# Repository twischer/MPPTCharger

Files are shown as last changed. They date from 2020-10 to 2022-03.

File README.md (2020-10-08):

# MPPTCharger
Maximum Power Point Tracking Charge Controller for ESP8266

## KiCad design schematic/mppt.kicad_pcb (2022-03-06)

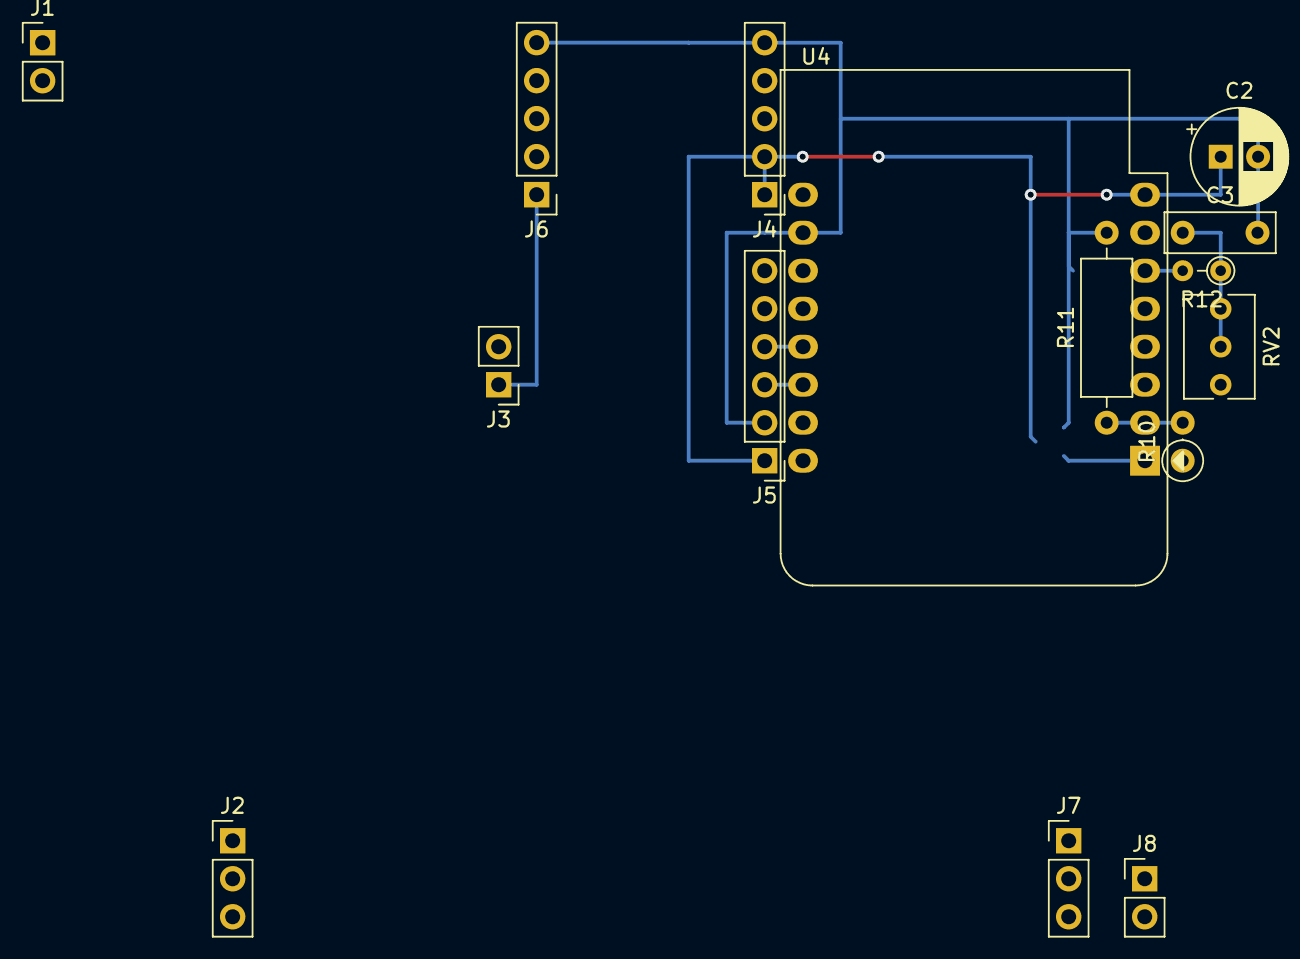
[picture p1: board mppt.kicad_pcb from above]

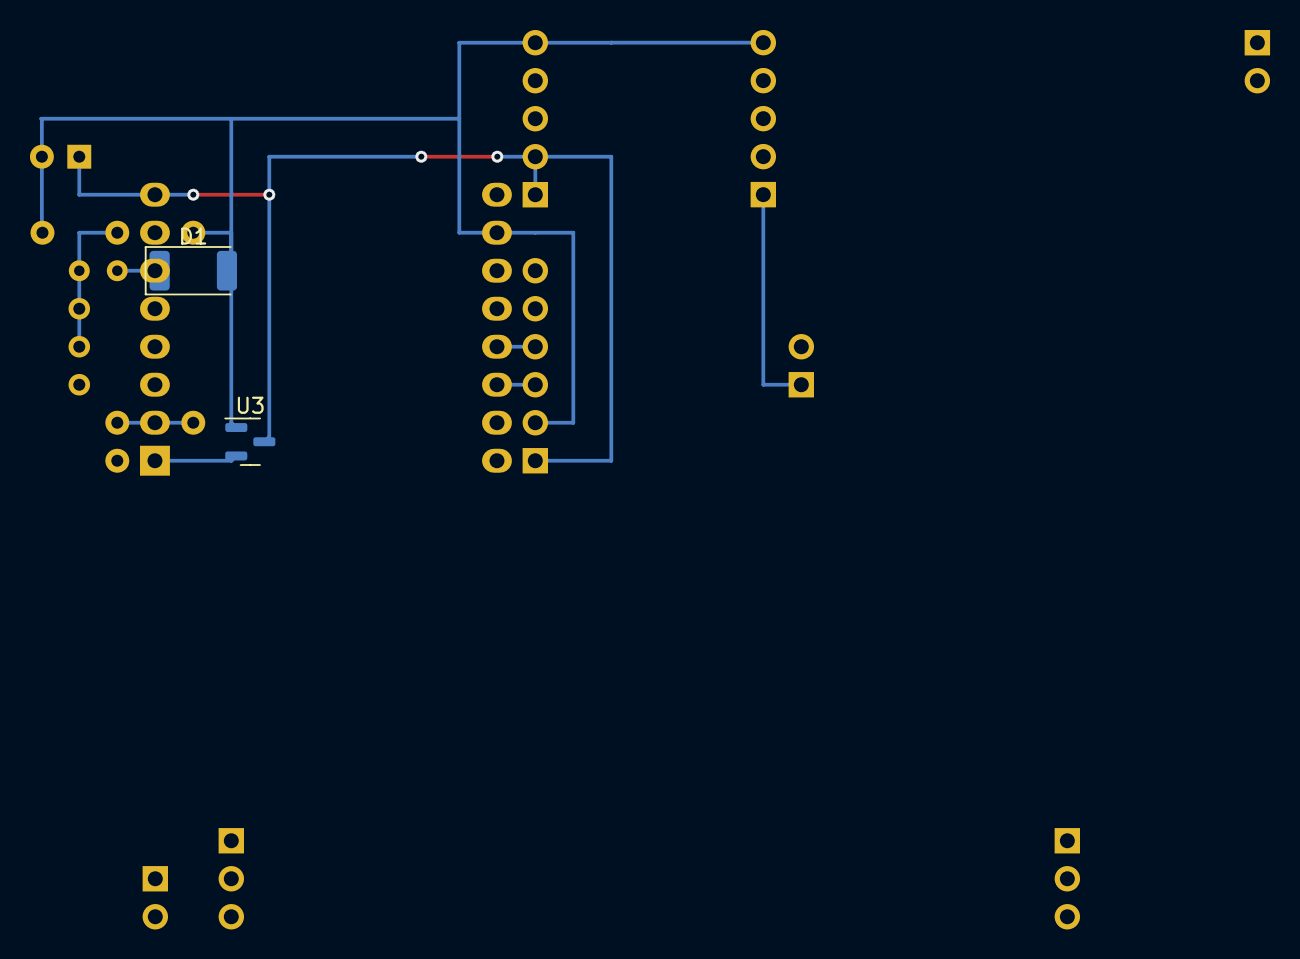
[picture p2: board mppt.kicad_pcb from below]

Board: 2 copper layers, 17 parts (2 on the bottom side), 12 nets.

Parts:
C2: 100µ; CP_Radial_D6.3mm_P2.50mm
C3: 1µ; C_Rect_L7.2mm_W2.5mm_P5.00mm_FKS2_FKP2_MKS2_MKP2
D1: 3V6; D_2010_5025Metric
J1: Solar; PinHeader_1x02_P2.54mm_Vertical
J2: TL494-IN; PinHeader_1x03_P2.54mm_Vertical
J3: INA219; PinHeader_1x02_P2.54mm_Vertical
J4: MP2307-OUT; PinHeader_1x05_P2.54mm_Vertical
J5: INA219; PinHeader_1x06_P2.54mm_Vertical
J6: MP2307-IN; PinHeader_1x05_P2.54mm_Vertical
J7: TL494-OUT-42V-3A; PinHeader_1x03_P2.54mm_Vertical
J8: LiIon-36V; PinHeader_1x02_P2.54mm_Vertical
R10: 120k; R_Axial_DIN0207_L6.3mm_D2.5mm_P2.54mm_Vertical
R11: 2k2; R_Axial_DIN0309_L9.0mm_D3.2mm_P12.70mm_Horizontal
R12: 1k2; R_Axial_DIN0204_L3.6mm_D1.6mm_P2.54mm_Vertical
RV2: 10k; Potentiometer_Bourns_3266Y_Vertical
U3: MAX809S; SOT-23
U4: WeMos_D1_mini; WEMOS_D1_mini_light

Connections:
GND: C2.2, C3.2, D1.2 (A), J1.1, J2.3, J4.5, J5.2, J6.5, R11.2, U3.1 (GND), U4.10 (GND)
unnamed: C2.1, J4.1, J4.2, J5.1, U3.3 (VCC), U4.8 (3V3)
unnamed: C3.1, R12.1, RV2.2, RV2.3
unnamed: D1.1 (K), R12.2, U4.6 (MOSI/D7)
unnamed: J7.1, R10.1
unnamed: J1.2, J3.2, J5.6
unnamed: J2.1, J3.1, J5.5, J6.1
unnamed: J5.3, U4.14 (SCL/D1)
unnamed: J5.4, U4.13 (SDA/D2)
unnamed: J7.3, J8.2
unnamed: R10.2, R11.1, U4.2 (A0)
unnamed: U3.2 (RESET), U4.1 (~RST)

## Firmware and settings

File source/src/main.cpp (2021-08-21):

#ifdef ESP8266
#include <ESP8266WiFi.h>
#else
#include <WiFi.h>
#endif

#include <wiring_private.h>
#include <GDBStub.h>
#include <TelnetStream.h>
#include <StreamUtils.h>
#include <WiFiManager.h>
#include <INA219Calc.hpp>
#include "SoftwareWatchdog.h"
#include "ADCReader.hpp"
#include "MPPT.hpp"
#include "MPPTSigmaDeltaOutput.hpp"

static const char AP_SSID[] = "MPPTCharger";
static const char AP_PASSWORD[] = "zweiundvierzig";

static const bool ENABLE_GDB_STUB = false;

static const uint8_t INA219_SCL = 2;
static const uint8_t INA219_SDA = 13;
static const float SHUNT_R = 0.005;
static const float SHUNT_MAX_V = 0.04;
static const float MAX_CURRENT = SHUNT_MAX_V / SHUNT_R;

static const float ADC_VOLTAGE_OUT_MIN = 33.0;
static const float ADC_VOLTAGE_OUT_MAX = 42.0;
static const float ADC_VOLTAGE_OUT_PROTECT = ADC_VOLTAGE_OUT_MAX * 1.01; /* max + 1% */

SoftwareWatchdog swWatchdog;
ADCReader adcs;
INA219Calc ina219;
/* GPIO12 is connected to dead time control of TL494 */
const uint8_t TL494_DTC_PIN = 12;
MPPTSigmaDeltaOutput mpptOutput(TL494_DTC_PIN);
MPPT mppt(mpptOutput);
WriteBufferingStream telnet(TelnetStream, 160);


static void outSwitchOff()
{
	digitalWrite(TL494_DTC_PIN, HIGH);
	pinMode(TL494_DTC_PIN, OUTPUT);
}

RF_PRE_INIT() {
	/* disable step up/down converter to keep initial solar power for ESP boot up */
	outSwitchOff();
}

/* do not reset GPIO pins between RF_PRE_INIT() and setup() */
void resetPins() {}

void setup()
{
	Serial.begin(115200);
	Serial.print("Reset reason: ");
	Serial.println(ESP.getResetInfo());

	if (ENABLE_GDB_STUB) {
		/* See https://arduino-esp8266.readthedocs.io/en/latest/gdb.html for usage */
		gdbstub_init();
	}

	WiFiManager wifiManager;
	/* do not block in Web interface when STA WiFi not available */
	wifiManager.setConfigPortalTimeout(1);
	/* connecting to wifi might take some time */
	swWatchdog.feed();
	wifiManager.autoConnect(AP_SSID, AP_PASSWORD);
	swWatchdog.feed();

	Wire.begin(INA219_SDA, INA219_SCL);
	ina219.begin();
	ina219.configure(INA219::RANGE_32V, INA219::GAIN_1_40MV, INA219::ADC_64SAMP,
			INA219::ADC_64SAMP, INA219::CONT_SH_BUS);
	ina219.calibrate(SHUNT_R, SHUNT_MAX_V, D_V_BUS_MAX, MAX_CURRENT);

	TelnetStream.begin();
}

static void updateTelnet()
{
	// TODO only execute the following when a client is connected */
	//if (!TelnetStream.available())
	//	return;

	/* clear screen and move to home position */
	telnet.print("\033[H\033[2J");
	telnet.println("ESP8266 MPPT Charger");

	const uint32_t seconds = millis() / 1000;
	const uint32_t minutes = seconds / 60;
	const uint32_t hours = minutes / 60;
	telnet.printf("Uptime:\t%02u:%02u:%02uh", hours, (minutes % 60), (seconds % 60));
	telnet.println();

	telnet.print("Uin:\t");
	telnet.print(ina219.busVoltage());
	telnet.println("V");

	telnet.print("Iin:\t");
	telnet.print(ina219.shuntCurrent());
	telnet.println("A");

	telnet.print("Pin:\t");
	telnet.print(ina219.busPower());
	telnet.println("W");

	telnet.print("Ein:\t");
	telnet.print(ina219.busEnergy());
	telnet.println("Wh");

	telnet.print("Uout:\t");
	const float uout = adcs.get(ADC_VOLTAGE_OUT);
	static bool outProtected = false;
	if (uout > ADC_VOLTAGE_OUT_PROTECT) {
		outSwitchOff();
		outProtected = true;
	}
	telnet.print(uout);
	telnet.print("V ");

	static const float voltage2level = 100 / (ADC_VOLTAGE_OUT_MAX - ADC_VOLTAGE_OUT_MIN);
	const float uoutBattStart = uout - ADC_VOLTAGE_OUT_MIN;
	const float chargeLevel = (uoutBattStart > 0) ? (uoutBattStart * voltage2level) : 0.0;

	telnet.print(chargeLevel);
	telnet.println("%");

	telnet.print("PWMout:\t");
	if (outProtected)
		telnet.println("PROTECTED!!!");
	else {
		const float pwm = mppt.getPwmLevel();
		telnet.print(pwm);
		telnet.print("% ");

		static float lastPWM = 0.0;
		if (pwm > lastPWM)
			telnet.println("u");
		else
			telnet.println("d");
		lastPWM = pwm;
	}
	telnet.flush();
}

void loop()
{
	switch (TelnetStream.read()) {
	case 'w':
	case 'W': {
		WiFiManager wifiManager;
		swWatchdog.disable();
		/* this call blocks until a WLAN was selected */
		wifiManager.startConfigPortal(AP_SSID, AP_PASSWORD);
		swWatchdog.enable();
		break;
	}
	case 'R':
		TelnetStream.stop();
		delay(100);
		ESP.restart();
		break;
	case 'e':
	case 'q':
	case 'c':
	case 'C':
		TelnetStream.println("bye bye");
		TelnetStream.flush();
		TelnetStream.stop();
		break;
	}


	const unsigned long now = millis();
	static unsigned long next = now;
	static uint8_t counter = 0;
	if (next < now) {
		next += 50;
		if (adcs.update()) {
			/* wait for averaging */
			// TODO may be high diffs will only be craeted on a certain PWM level
			// therefore avarage over multiple PWM levels
				mppt.update(ina219.busVoltage(),
					ina219.busPower());
			if (counter > 6) {
				counter = 0;
				/* print values when desition was made */
				updateTelnet();
				swWatchdog.feed();
			}
			counter++;
		}
	}

}

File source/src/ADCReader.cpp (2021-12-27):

#include "ADCReader.hpp"

const ADCReader::adc2unit_t ADCReader::adc2unit[ADC_MAX] = {
	[ADC_CURRENT_IN] = {
		.offset = -31.11894,
		.gain = 0.04245421,
	},
	[ADC_VOLTAGE_IN] = {
		.offset = -0.1009902,
		.gain = 0.02524754,
	},
	[ADC_VOLTAGE_OUT] = {
		.offset = -0.1384028,
		.gain = 0.05386298,
	},
};

ADC_MODE(ADC_TOUT_3V3)

/**
 * @return true when all ADC values were updated once
 */
bool ADCReader::update()
{
	for (int i=0; i<16; i++) {
		const float adc = analogRead(A0);

		const adc2unit_t& a2u = adc2unit[nextChannel];
		const float value = adc * a2u.gain + a2u.offset;
		const float limitedValue = (value < 0.0) ? 0.0 : value;
		values[nextChannel].update(limitedValue);
	}

	nextChannel++;
	if (nextChannel >= ADC_MAX)
		nextChannel = 0;

	for (uint8_t i=0; i<ARRAY_SIZE(ADC_CH_SEL_PINS); i++) {
		const uint32_t mask = 1 << ADC_CH_SEL_PINS[i];
		if (nextChannel & (1 << i))
			GPOS = mask;
		else
			GPOC = mask;
	}

	return (nextChannel == 0);
}

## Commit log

2020-11-02 Add schematic and basic source
    [mppt.kicad_pcb, mppt.sch]
2020-11-02 ADCReader: Always add offset to ADC values
2020-11-02 Add maximal power point tracking algo
2020-11-02 Provide class to calculate power and energy
2020-11-02 mppt: Use right sigma delta channel for attaching
2020-11-04 adc: Set offsets
2020-11-04 schematic: Use rsistor for DTC connection to limit current to TL494 capacitor
    [mppt.kicad_pcb, mppt.sch]
2020-11-04 Non negativ charge level and PWM level
2020-11-04 mppt: Use min sigma delta freqency of 156kHz
    In case of 312,5kHz the worst case frequency can be up to 40MHz.
    This seams to crash the ESP. At least the telnet session is not updating
    anymore
2020-11-07 Wait for Avarage and print after desition
2021-01-05 adc: calucalte in float and avarage
2021-01-05 adc: capture 16 samples per channel before moving to next channel
2021-01-05 make printing faster
2021-01-05 schematic: Add 100nF capacitors
    [mppt.kicad_pcb, mppt.sch]
2021-01-05 Print PWM direction
2021-01-05 Add SW watchdog only triggered after print
    Ensures that ESP woudl reset in case anything up to Print is not working
    [main.cpp]
2021-01-05 fixup! adcclacl: caluclate everything in float
    [main.cpp]
2021-01-05 Use ArduinoINA219
2021-01-05 schematic: Use INA219
    [mppt.kicad_pcb, mppt.sch]
2021-01-05 Swap GPIO0 and GPIO13
    [mppt.kicad_pcb, mppt.sch]
2021-01-05 schematic: Reduce GPIO15 pull down to 2,2kOhm
    [mppt.kicad_pcb, mppt.sch]
2021-01-05 adc: Adapt out voltage to max charge voltage
    messearued by Fluke multimeter.
    100mV underneath max charge voltage.
    ADC value before this patch: 41,76V
    Mesured by Fluke multimeter: 41,9V
2021-01-05 Switch step up of when output voltage exceeds max + 1%
2021-01-05 ina219calc: Calculate and print the energy
2021-01-05 Print up time of ESP8266
2021-04-17 schematic: Supply ESP from battery
    When the ESP is supplied by the solar panel it starts quite late on
    raising sun. As long as the ESP is not running the step up converter is
    running. It drains so much power that the supply voltage for the ESP is
    to low.
    [mppt.sch]
2021-12-27 Support d1 Mini board
2022-03-02 Update to KiCad 6.0
    [mppt.kicad_pcb]
2022-03-06 sch: Use error amp of TL494 for MPPT
    [mppt.kicad_pcb, mppt.kicad_sch]
